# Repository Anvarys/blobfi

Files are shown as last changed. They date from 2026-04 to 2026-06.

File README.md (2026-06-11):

<div align="center">
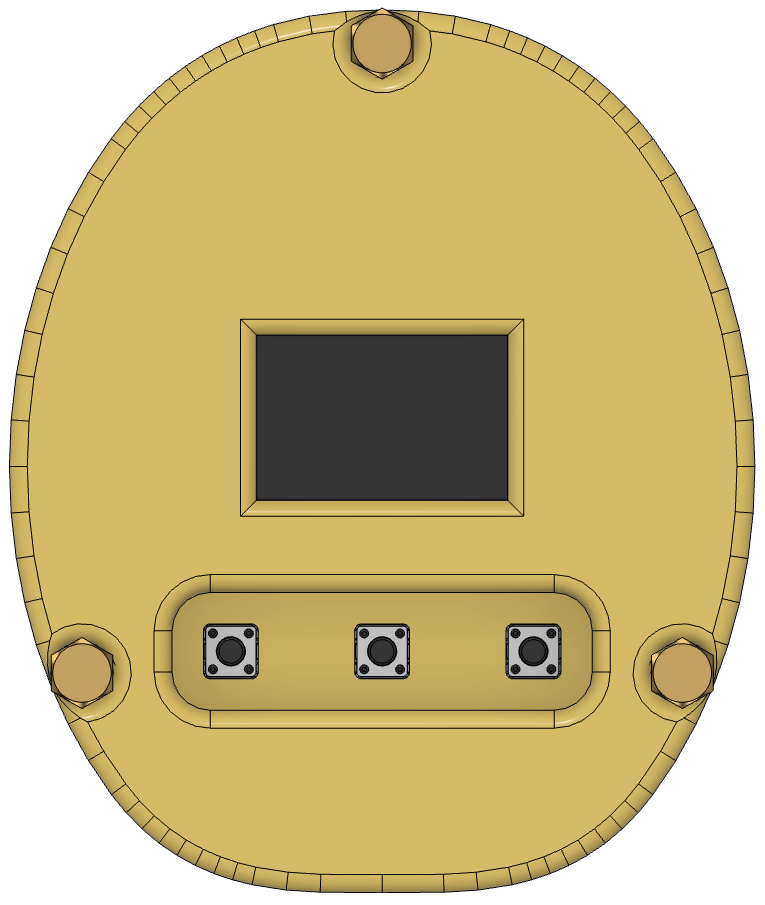
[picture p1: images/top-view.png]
Blobfi
  
</div>

<h2 align="center">Blobfi</h2>
<p align="center">
A custom PCB-based Tamagotchi virtual pet called Blobfi
</p>

## About the project

A custom PCB-based Tamagotchi-like virtual pet built the XIAO-ESP32-C6 MCU, featuring a 0.96" OLED display, 500mah battery with USB-C charging (via the esp32), 3 buttons, a temperature sensor and a vibration motor.

I made this project to have my own custom tamagotchi pet called Blobfi, which is a blobfish, because I love blobfishes!!

I used [Tanishq's tamagotchi](https://github.com/TaniWanKenobi/tamagotchi/) as insiration & reference.

## How to build your own Blobfi

To build this project yourself, first you need to 3d print the top and bottom parts ([link to the folder with 3d models](https://github.com/Anvarys/blobfi/tree/master/CAD)), also you preferably should print 4 of the screen supports that will be used to mount hold the screen parallel to the PCB. Then you need to buy all the [parts](https://github.com/Anvarys/blobfi/blob/master/BOM.csv) and the [PCB](https://github.com/Anvarys/blobfi/blob/master/blobfi_gerber.zip) and then assemple it all together as shown on the picture below (also you need to screw the PCB and the top to the bottom enclosure in using 3 M3x8mm screws each):
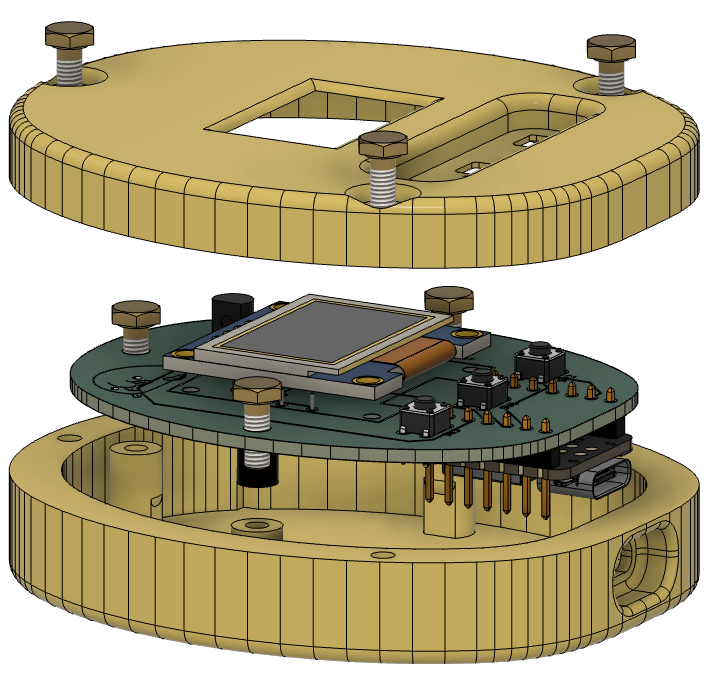
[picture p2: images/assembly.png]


And then you need to flash the ESP32 using my [blobfi_firmware](https://github.com/Anvarys/blobfi/tree/master/blobfi_firmware) sketch in Arduino IDE, also you need to install Adafruit SSD1306, OneWireNg, DallasTemperature libraries with their dependencies.

## Tools I used

For PCB & schematic design I used [KiCAD](https://kicad.org), for 3D design I used [Autodesk Fusion](https://www.autodesk.com/products/fusion-360/overview) (free version), for coding the firmware I used [Arduino IDE](https://www.arduino.cc/en/software/), for testing the firmware I used [Wowki](https://wokwi.com/) hardware simulator and for general design (Edge.Cuts & the Zine) I used [Figma](https://figma.com)

## PCB design

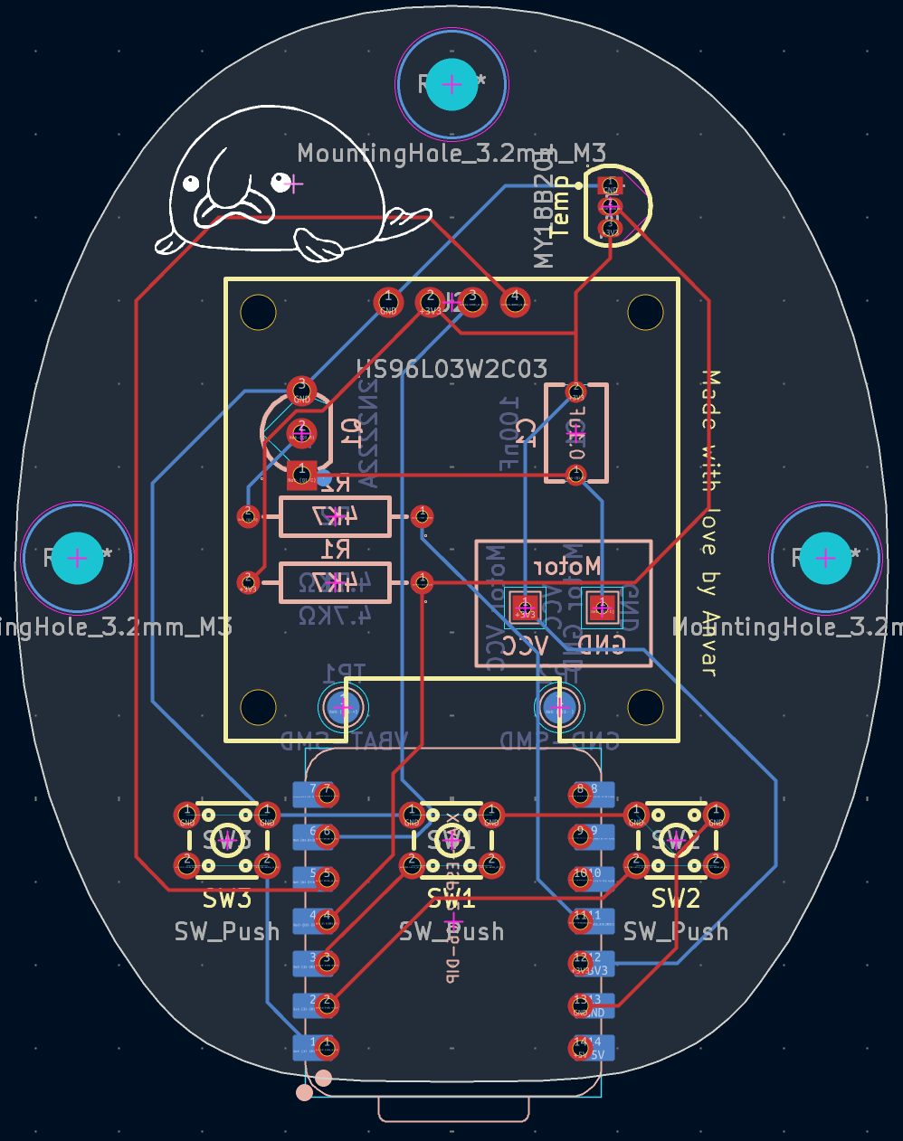
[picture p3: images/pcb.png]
pcb


## Schematic

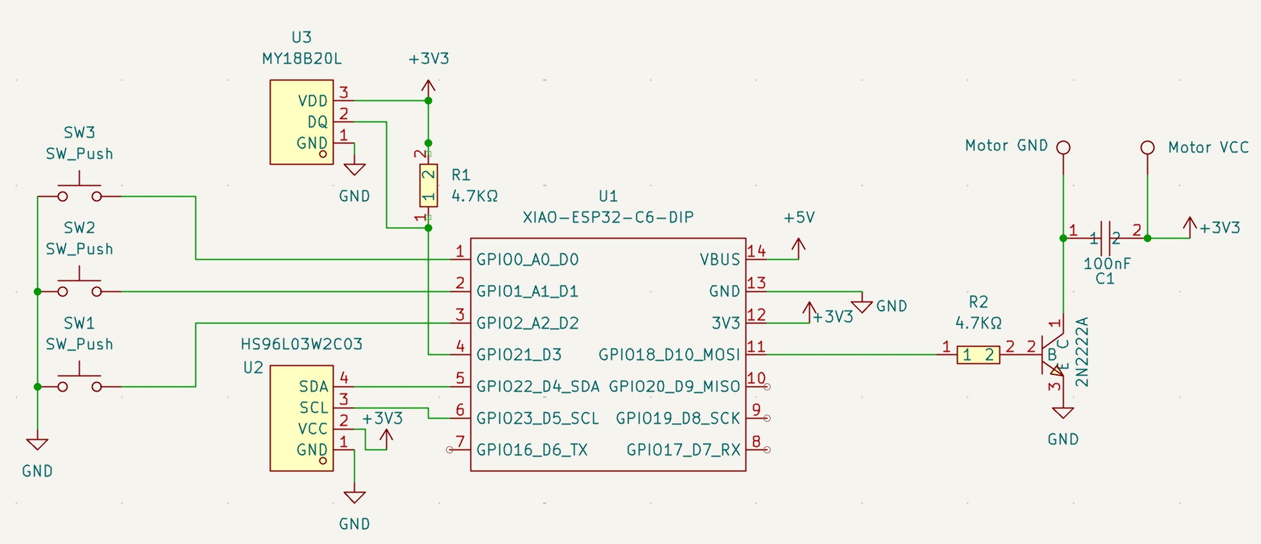
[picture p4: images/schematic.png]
schematic


## 3D model

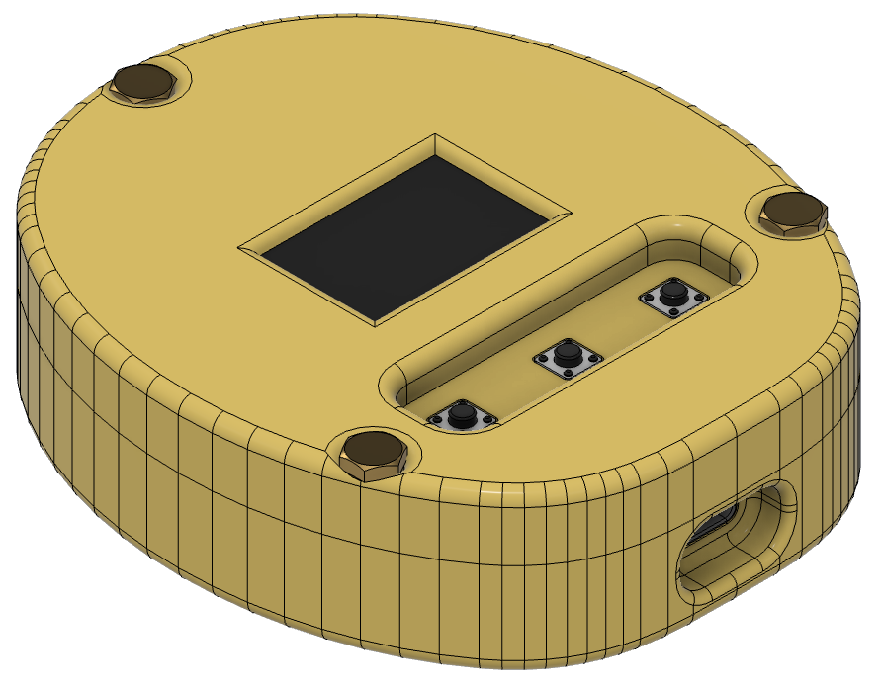
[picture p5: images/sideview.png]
3d model


## Firmware

Blobfi has 3 stats which decrease by 1 each 5 minutes:
- Hunger
- Happiness
- Energy

And if the temperature of Blobfi goes above 40C or below 5C happiness will decrease at 2x rate.

Depending on these stats you will have a different image of a blobfish on your main screen, here is an example of a happy Blobfi:

Emulated render:
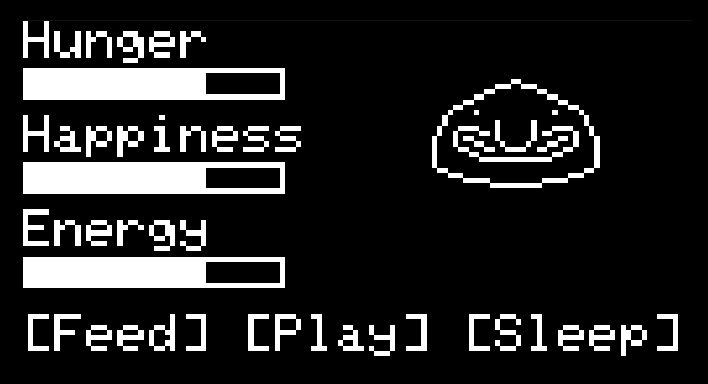
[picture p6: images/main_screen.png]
main_screen


An actual photo:
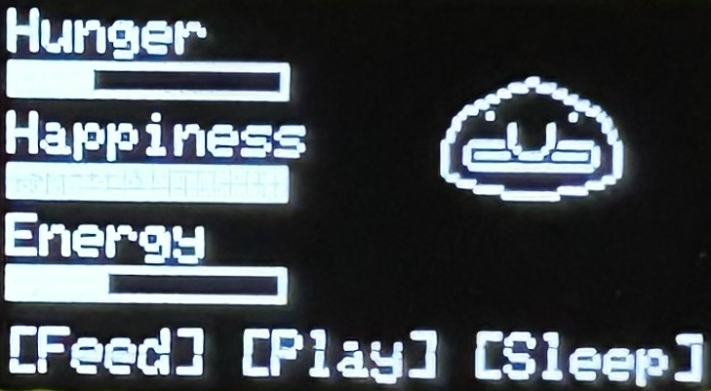
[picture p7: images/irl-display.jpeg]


If any of the stats will go below 0 it will be set to 0 and the vibration motor will shake your Blobfi as it wants to eat/sleep/play.

Also if any stat is below 10 then the bar will blink on the screen.

Actions buttons do:
- Left button: Feed Blobfi, +15 hunger and +5 energy
- Middle button: Play with Blobfi, +15 happiness and -5 energy
- Right button: Put Blobfi to sleep, +15 energy
- Left and right buttons at the same time: Put the device into deep sleep (basically turning it off, you can wake it up by pressing any button)

And here is an example of an action animation (duration - 3s):

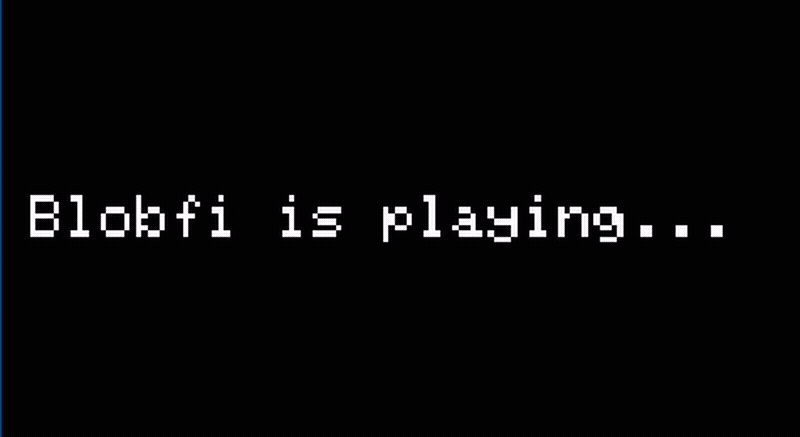
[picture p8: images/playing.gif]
playing animation


#### Deep sleep

Also my firmware uses ESP32 deep sleep feature, which allows it to go into a very low power use mode. After 30 seconds of inactivity (not pressing any buttons) the device will go into deep sleep.

When the device goes into deep sleep it will disable the display, but it will start an internal timer for the next update of Blobfi (5 minutes minus the time from the last update that had already passed) and it will still listen to any button inputs, and if you press any button it will wake up to the normal state.

This allows to reduce ESP32C6 and display's total current from about **50mA** to about **17µA** which is around **2941 times less current**. This allows for the device to actually work for longer than some 10-15 hours, now it can do multiple weeks (theoretically months, has not tested that in practice yet).

## BOM

|Name |Price (Total)|Link |
|---|---|---|
|Lithium battery 500mah |US$6.73 |https://fr.aliexpress.com/item/1005009540712263.html|
|XIAO ESP32 C6 |US$6.71 |https://fr.aliexpress.com/item/1005006987272421.html|
|M3 8mm screws |US$3.55 |https://fr.aliexpress.com/item/1005010597960014.html|
|Aliexpress shipping |US$5.10 |- |
|JLCPCB PCB |US$2.00 |https://jlcpcb.com |
|JLCPCB shipping & customs|US$2.20 |- |
|4K7 Resistor |US$0.58 |https://www.lcsc.com/product-detail/C119339.html |
|MY18B20L temp sensor |US$1.94 |https://www.lcsc.com/product-detail/C5259249.html |
|0.96'' OLED display |US$2.25 |https://www.lcsc.com/product-detail/C5248080.html |
|Tactile button |US$0.54 |https://www.lcsc.com/product-detail/C2888493.html |
|Vibration motor |US$0.52 |https://www.lcsc.com/product-detail/C2759982.html |
|Male pin headers (20pcs) |US$0.60 |https://www.lcsc.com/product-detail/C49261205.html  |
|2N2222A transistor |US$0.90 |https://www.lcsc.com/product-detail/C5330385.html |
|0.1uF capacitor |US$0.61 |https://www.lcsc.com/product-detail/C5632427.html |
|LCSC shipping & handling |US$12.57 |- |
| | | |
|Total |US$46.80 | |

The display is out of stock so the price is for buying one from "Other suppliers" on LCSC

## Build photos

For reference the squares are 5x5mm

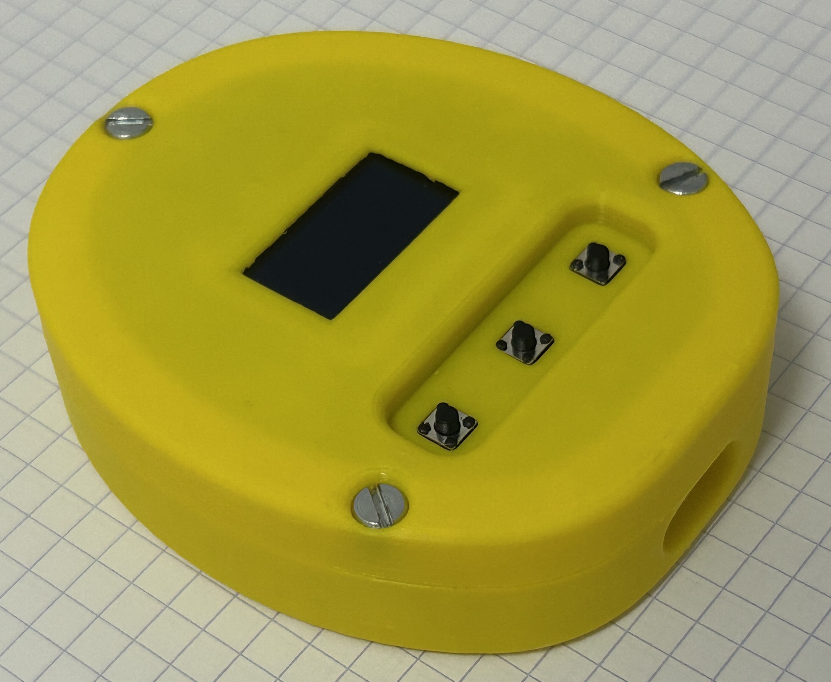
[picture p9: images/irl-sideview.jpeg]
sideview


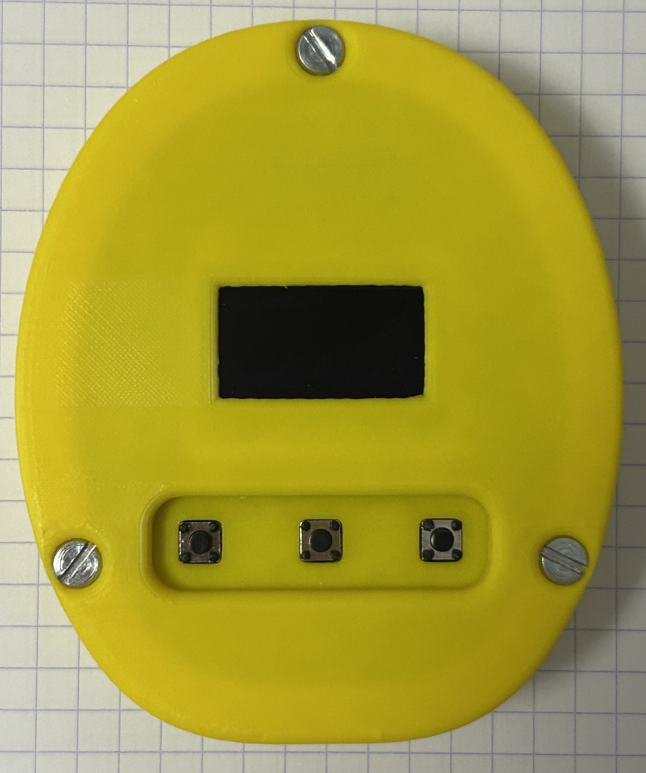
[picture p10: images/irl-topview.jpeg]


[_demo_](https://www.youtube.com/shorts/axdSh3g87GE)

## My zine for this project

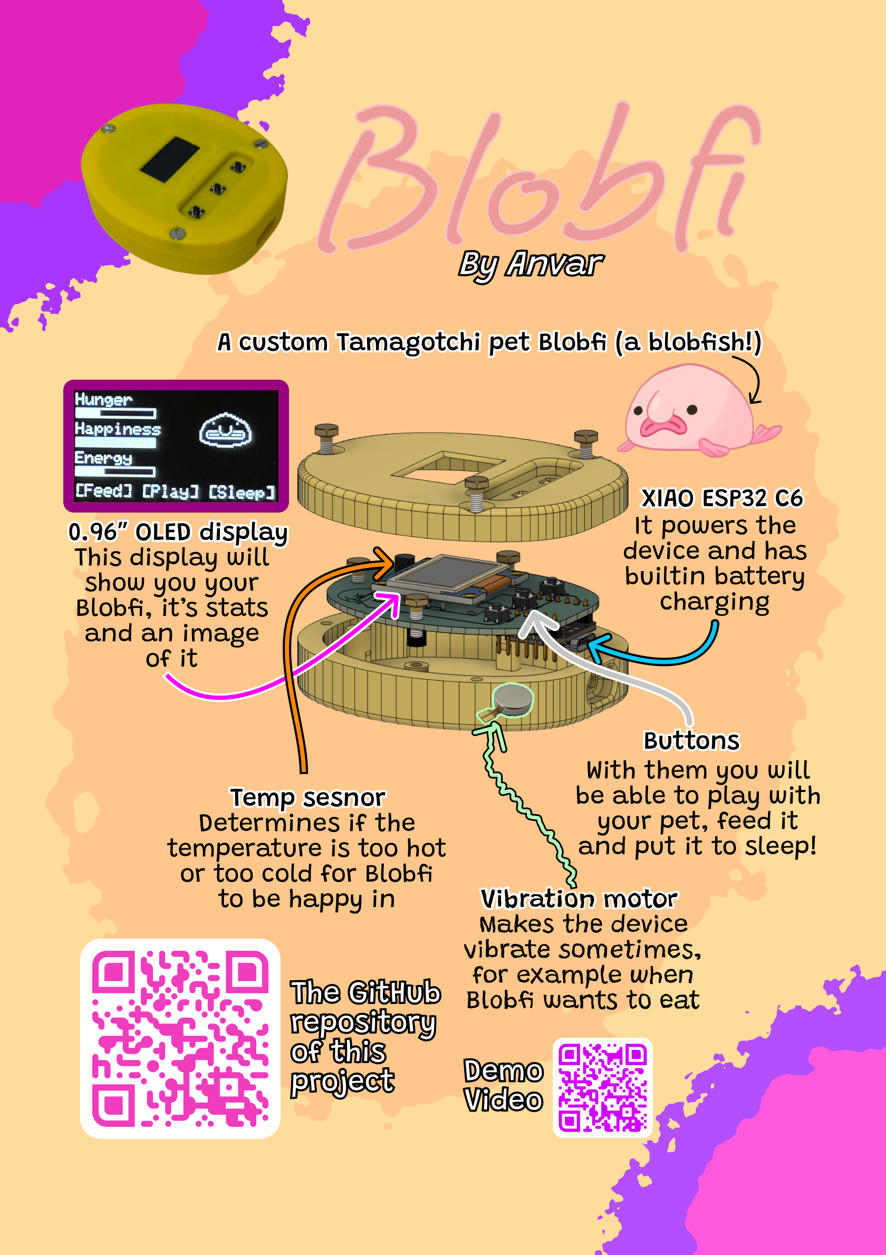
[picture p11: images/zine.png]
Zine


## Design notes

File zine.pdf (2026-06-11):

## Blobfi By Anvar

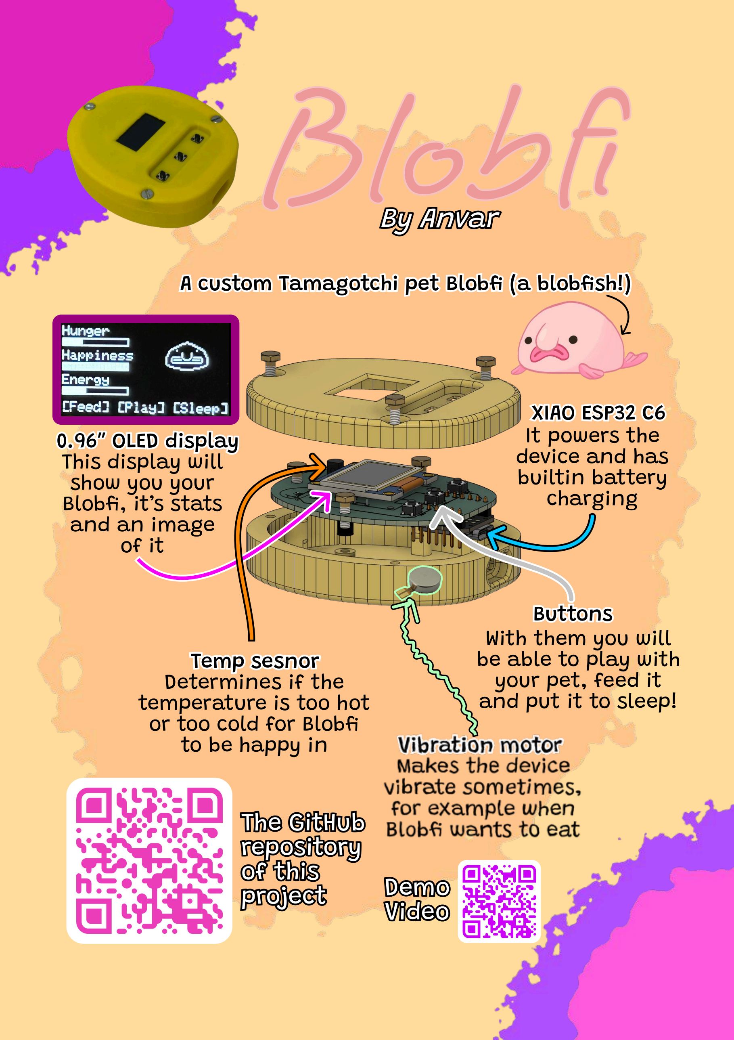
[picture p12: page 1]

A custom Tamagotchi pet Blobfi (a blobfish!)

0.96’’ OLED display This display will show you your Blobfi, it’s stats and an image of it

XIAO ESP32 C6
It powers the device and has builtin battery

charging

Determines if the temperature is too hot or too cold for Blobfi to be happy in

Temp sesnor

### The GitHub repository of this

project

aes the device vibrate sometimes, for eample when Blobfi wants to eat

### Demo

Video

ibration motor

Buttons
With them you will be able to play with your pet, feed it and put it to sleep!

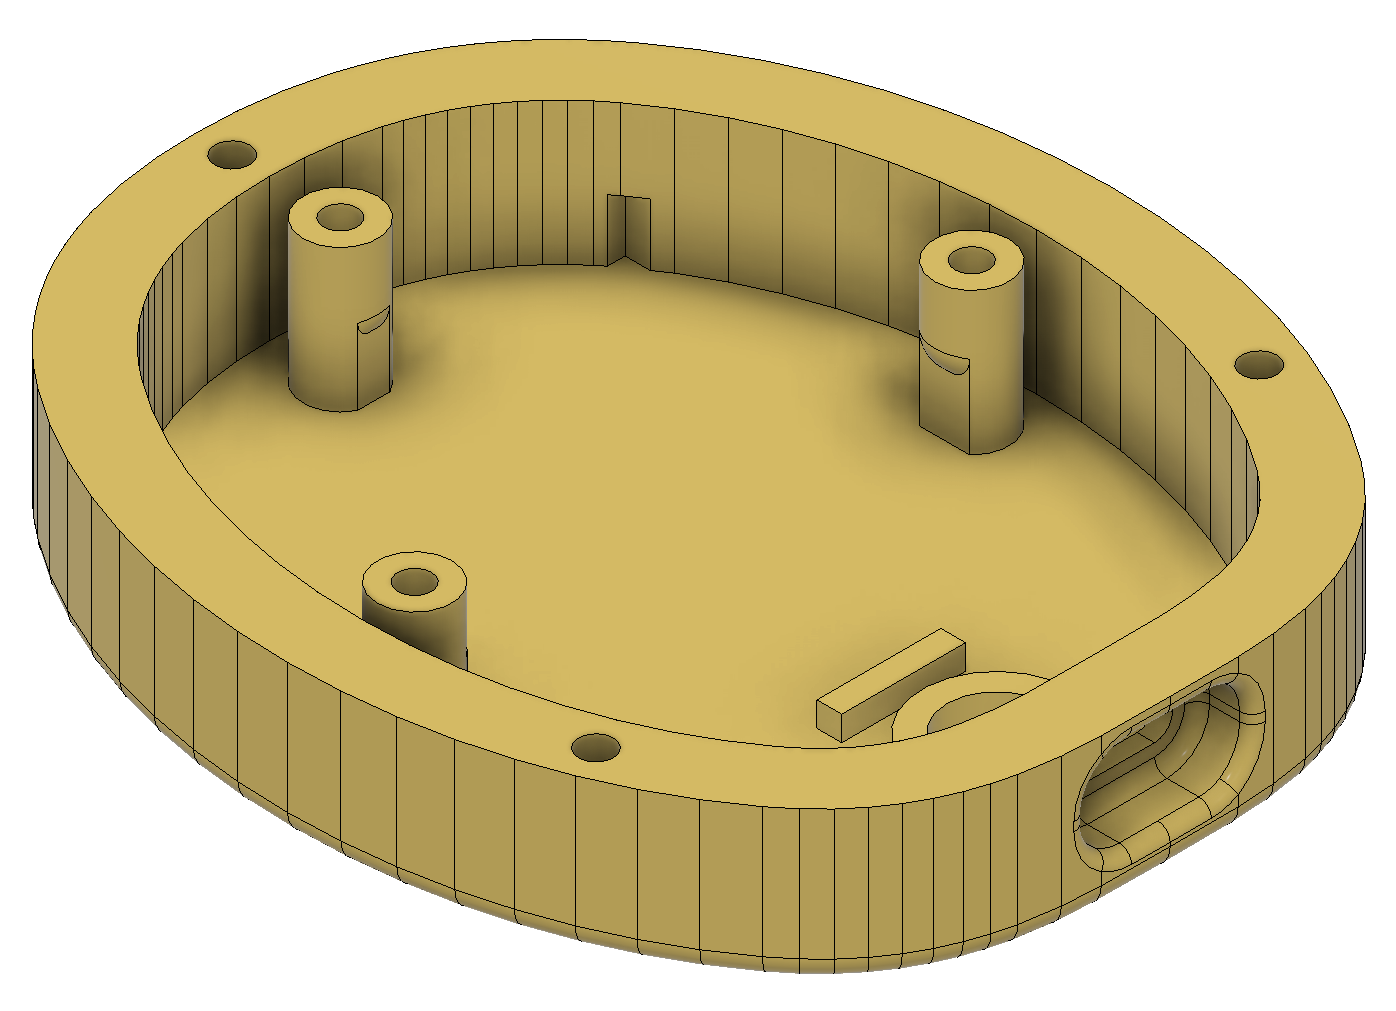
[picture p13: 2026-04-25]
images/bottom-3d-model.png

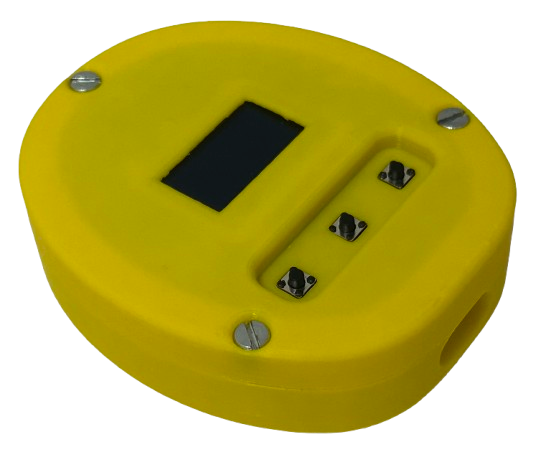
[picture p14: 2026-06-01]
images/irl-sideview-no-bg.png

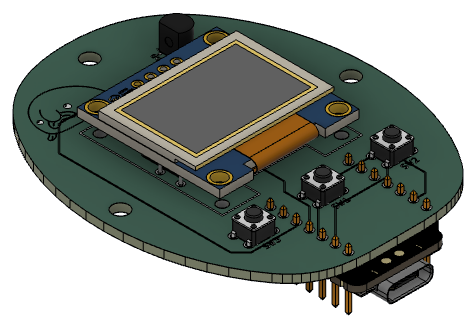
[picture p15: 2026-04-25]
images/pcb-3d-model.png

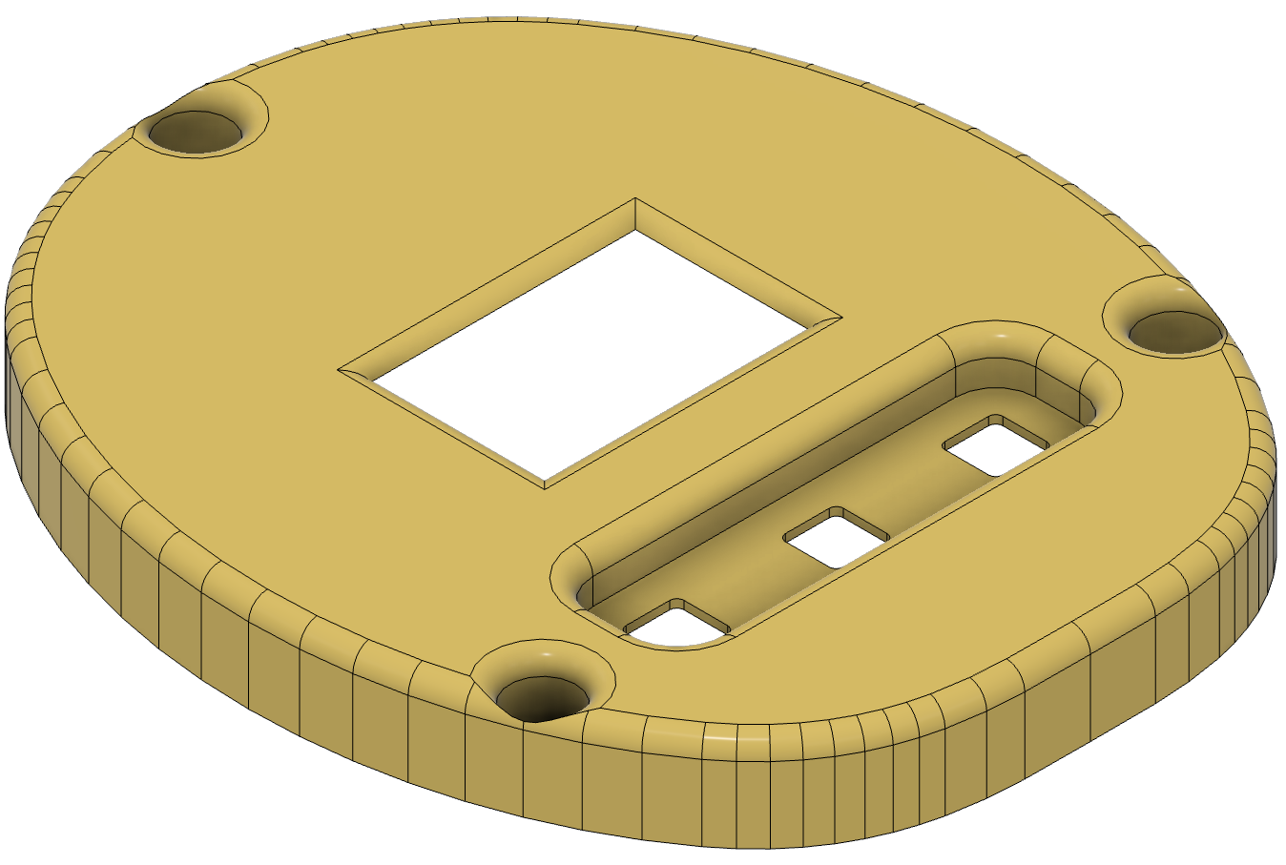
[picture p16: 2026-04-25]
images/top-3d-model.png

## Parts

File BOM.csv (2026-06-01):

Name | Qty needed | Qty bought | Link | Price (Qty bought) | Running total | Note
LED driver | 1 | 1 | https://www.lcsc.com/product-detail/C157417.html | US$3.29 | US$3.29
LED | 72 | 80 | https://www.lcsc.com/product-detail/C17215415.html | US$0.94 | US$4.23
RP2040 MCU | 1 | 1 | https://www.lcsc.com/product-detail/C2040.html | US$0.95 | US$5.18
USB-C PD controller | 1 | 1 | https://www.lcsc.com/product-detail/C970725.html | US$0.61 | US$5.79
USB-C port | 1 | 5 | https://www.lcsc.com/product-detail/C7463258.html | US$1.20 | US$6.99
Step-down buck converter to 3.3V | 1 | 1 | https://www.lcsc.com/product-detail/C60726.html | US$1.32 | US$8.31
12MHz crystal | 1 | 5 | https://www.lcsc.com/product-detail/C2901650.html | US$0.38 | US$8.69
32Mbit flash | 1 | 1 | https://www.lcsc.com/product-detail/C179173.html | US$1.66 | US$10.35 | can be interchanged with any memory size of the same family (up to 128Mbit)
RTC IC | 1 | 1 | https://www.lcsc.com/product-detail/C107410.html | US$3.01 | US$13.36
Coin battery holder | 1 | 1 | https://www.lcsc.com/product-detail/C7501066.html | US$0.82 | US$14.18
6P Socket for the display | 1 | 6 | https://www.lcsc.com/product-detail/C2897388.html | US$0.99 | US$15.17
Step-down buck converter to 10.5V | 1 | 5 | https://www.lcsc.com/product-detail/C52653.html | US$2.03 | US$17.20
Capacitive touch IC | 3 | 3 | https://www.lcsc.com/product-detail/C91322.html | US$9.56 | US$26.76
Buzzer | 1 | 1 | https://www.lcsc.com/product-detail/C255333.html | US$1.17 | US$27.93
NPN transitor | 1 | 5 | https://www.lcsc.com/product-detail/C7603172.html | US$0.04 | US$27.97
AO3401A | 1 | 10 | https://www.lcsc.com/product-detail/C15127.html | US$0.59 | US$28.56
AO3400A | 1 | 5 | https://www.lcsc.com/product-detail/C20917.html | US$0.41 | US$28.97
3.3uH inductor | 2 | 5 | https://www.lcsc.com/product-detail/C167219.html | US$0.85 | US$29.82
B220A diode | 2 | 5 | https://www.lcsc.com/product-detail/C110481.html | US$0.47 | US$30.29
Tactile button | 1 | 10 | https://www.lcsc.com/product-detail/C49140441.html | US$0.42 | US$30.71
6.8pF capacitor | 1 | 50 | https://www.lcsc.com/product-detail/C318672.html | US$0.53 | US$31.24
15pF capacitor | 2 | 100 | https://www.lcsc.com/product-detail/C1644.html | US$0.60 | US$31.84
180pF capacitor | 1 | 100 | https://www.lcsc.com/product-detail/C107041.html | US$0.43 | US$32.27
10nF capacitor | 1 | 50 | https://www.lcsc.com/product-detail/C1589.html | US$0.20 | US$32.47
0.1uF capacitor | 20 | 50 | https://www.lcsc.com/product-detail/C15725.html | US$0.35 | US$32.82
1uF capacitor | 4 | 50 | https://www.lcsc.com/product-detail/C5199872.html | US$0.45 | US$33.27
2.2uF capacitor | 1 | 10 | https://www.lcsc.com/product-detail/C19110.html | US$0.19 | US$33.46
10uF capacitor | 3 | 10 | https://www.lcsc.com/product-detail/C9807.html | US$0.39 | US$33.85
22uF capacitor | 2 | 10 | https://www.lcsc.com/product-detail/C602037.html | US$0.43 | US$34.28
27Ω resistor | 3 | 100 | https://www.lcsc.com/product-detail/C25190.html | US$0.15 | US$34.43
249Ω ±0.1% resistor | 3 | 10 | https://www.lcsc.com/product-detail/C870575.html | US$0.73 | US$35.16 | ±0.1% because it controls LED driver's max output intensity
1kΩ resistor | 2 | 100 | https://www.lcsc.com/product-detail/C2907113.html | US$0.11 | US$35.27
1kΩ 500mW resistor | 2 | 2 | https://www.lcsc.com/product-detail/C966306.html | US$0.01 | US$35.28 | R1, R2: usb-c PD, required ≥400mW
10kΩ resistor | 6 | 20 | https://www.lcsc.com/product-detail/C95204.html | US$0.44 | US$35.72 | ±0.1% resistor, not required but recommended for R26, controls the 10.5V Vout of a converter
4.7kΩ resistor | 2 | 100 | https://www.lcsc.com/product-detail/C2907034.html | US$0.12 | US$35.84
100kΩ ±0.1% resistor | 2 | 20 | https://www.lcsc.com/product-detail/C122538.html | US$0.45 | US$36.29 | ±0.1% because it controls 3.3V Vout of a converter (R5)
1MΩ resistor | 1 | 100 | https://www.lcsc.com/product-detail/C2907115.html | US$0.11 | US$36.40
75kΩ resistor | 3 | 100 | https://www.lcsc.com/product-detail/C114636.html | US$0.16 | US$36.56
47kΩ resistor | 1 | 100 | https://www.lcsc.com/product-detail/C105579.html | US$0.16 | US$36.72
316kΩ ±0.1% resistor | 1 | 20 | https://www.lcsc.com/product-detail/C861833.html | US$0.55 | US$37.27 | ±0.1% because it controls 3.3V Vout of a converter (R6)
121kΩ resistor | 1 | 20 | https://www.lcsc.com/product-detail/C861095.html | US$0.52 | US$37.79 | ±0.1% resistor, not required but recommended for R27, controls the 10.5V Vout of a converter
LCSC FedEx fast shipping |  |  | - | US$29.40 | US$67.19 | Without fast shipping I won't be able to build it in time
LCSC shipping coupon |  |  |  | -US$5.00 | US$62.19
JLCPCB PCB + stencil | 1 | 5 | https://jlcpcb.com | US$18.21 | US$80.40
JLCPCB DHL fast shipping |  |  | - | US$24.94 | US$105.34
JLCPCB customs |  |  |  | US$6.63 | US$111.97
JLCPCB shipping coupon |  |  |  | -US$10.00 | US$101.97 | New user shipping coupon
M2.5 5mm screws | 9 | 50 | https://www.amazon.fr/Inovey-Stainless-Hexagon-Ultrathin-Socket/dp/B0D59JTN94 | US$5.85 | US$107.82 | flat head, must have: dk <= 6.5mm && k <= 1.4mm | there are cheaper options on aliexpress, but if you need it to ship fast, amazon is the cheapest option
M3 6mm screws | 5 | 50 | https://www.amazon.fr/Inovey-Stainless-Hexagon-Ultrathin-Socket/dp/B0D59JTN94 | US$5.85 | US$113.67 | flat head, must have: dk <= 6.5mm && k <= 1.4mm | there are cheaper options on aliexpress, but if you need it to ship fast, amazon is the cheapest option
Waveshare 2.42" display | 1 | 1 | https://www.amazon.fr/Waveshare-Resolution-Communication-Compatible-Raspberry/dp/B0CL6WMHJN | US$25.64 | US$139.31 | there are cheaper options on aliexpress, but if you need it to ship fast, amazon is the cheapest option
Fan 12V | 1 | 1 | https://fr.aliexpress.com/item/1005002566049059.html | US$2.87 | US$142.18
3D printing Filament | 80g | 1kg | https://www.amazon.fr/ELEGOO-Imprimante-Précision-Dimensionnelle-Imprimantes/dp/B0D4Z8QT5T | US$21.04 | US$163.22 | preferably matte
Total |  |  |  | US$163.22

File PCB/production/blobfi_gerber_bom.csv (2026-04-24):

Designator | Footprint | Quantity | Value | LCSC Part #
C1 | CAP-TH_L5.8-W3.6-P5.0-D0.6 | 1 | 100nF | C5632427
GND | TestPoint_THTPad_1.5x1.5mm_Drill0.7mm | 1 | Motor GND
Q1 | TO-92-3_L4.8-W3.7-P2.54-R | 1 | 2N2222A | C5330385
R1, R2 | RES-TH_BD2.3-L6.5-P10.50-D0.5 | 2 | 4.7KΩ | C119339
SW1, SW2, SW3 | SW-TH_4P-L4.5-W4.5-P3.00-LS4.8 | 3 | SW_Push
TEMP | TO-92-3_L4.8-W3.7-P1.27-L | 1 | MY18B20L | C5259249
TP1 | TestPoint_Pad_D2.0mm | 1 | VBAT-SMD
TP2 | TestPoint_Pad_D2.0mm | 1 | GND-SMD
U1 | XIAO-ESP32-C6-DIP | 1 | XIAO-ESP32-C6-DIP
U2 | OLED-TH_L27.8-W27.2-P2.54_C9900033791 | 1 | HS96L03W2C03 | C5248080
VCC | TestPoint_THTPad_1.5x1.5mm_Drill0.7mm | 1 | Motor VCC

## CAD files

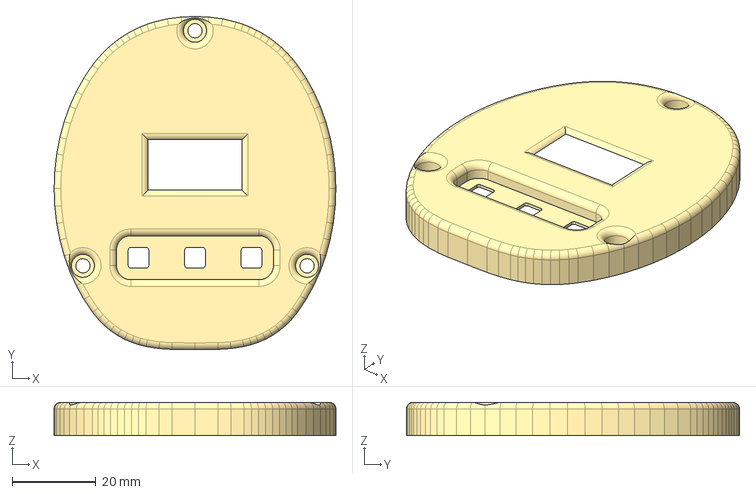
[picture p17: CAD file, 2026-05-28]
CAD/top-part.step
67.3 x 79.6 x 8.00 mm

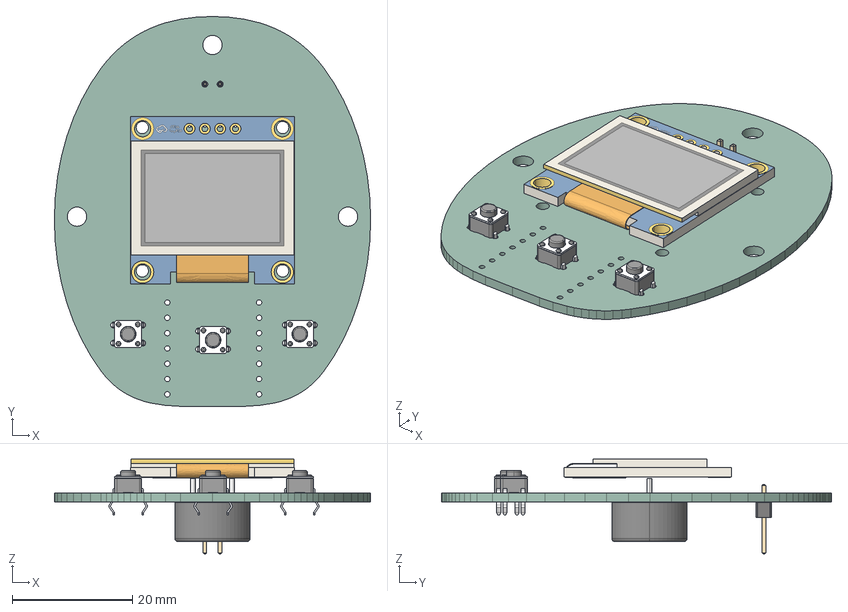
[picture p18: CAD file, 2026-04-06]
PCB/export/blobfi_pcb.step
52.5 x 64.8 x 15.7 mm
OLED-TH_L27.8-W27.2-P2.54_C9900033791
BUZ-TH_BD12.5-H7.0-P6.5
PinHeader_1x02_P2.54mm_Vertical
blobfi_PCB

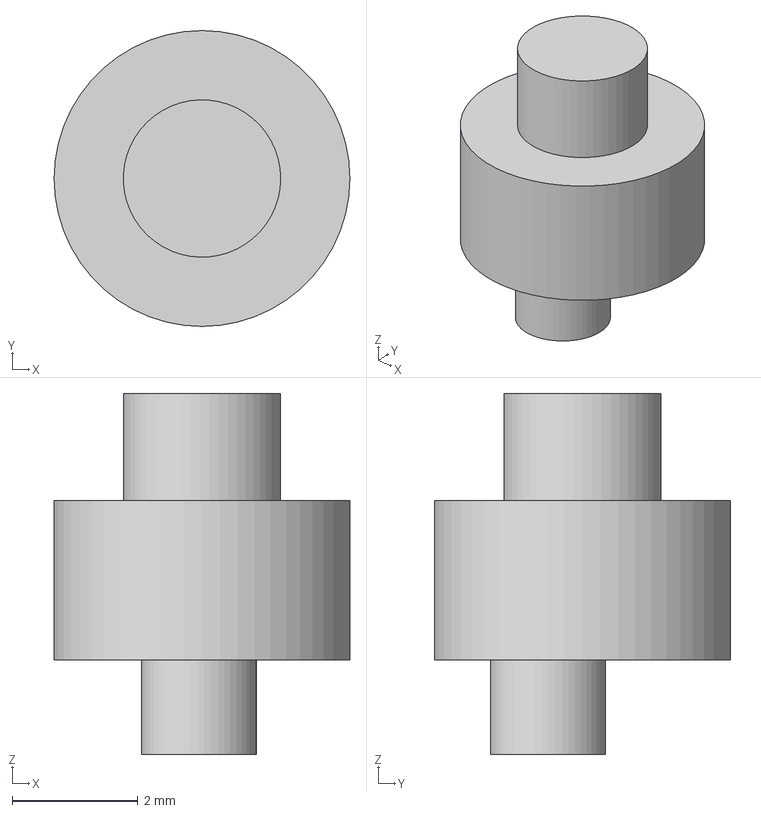
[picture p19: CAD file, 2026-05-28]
CAD/screen-support.step
4.70 x 4.70 x 5.74 mm

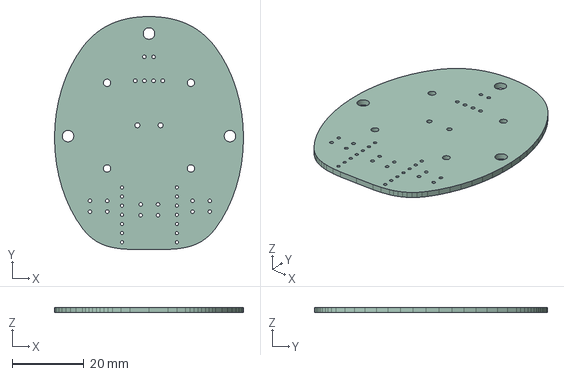
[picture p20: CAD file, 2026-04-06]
PCB/export/blobfi_pcb_only.step
52.5 x 64.8 x 1.51 mm

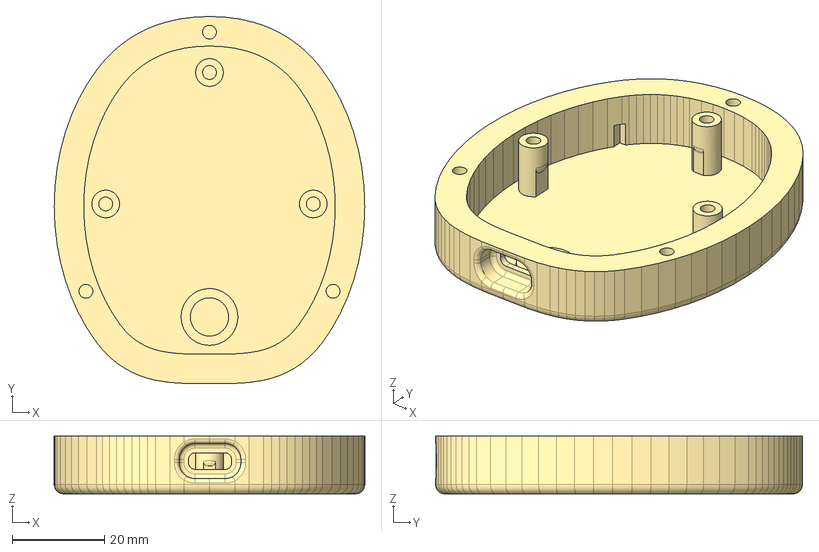
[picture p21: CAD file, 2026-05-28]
CAD/bottom-part.step
67.3 x 79.6 x 12.5 mm

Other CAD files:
CAD/bottom-part.f3d
CAD/top-part.f3d

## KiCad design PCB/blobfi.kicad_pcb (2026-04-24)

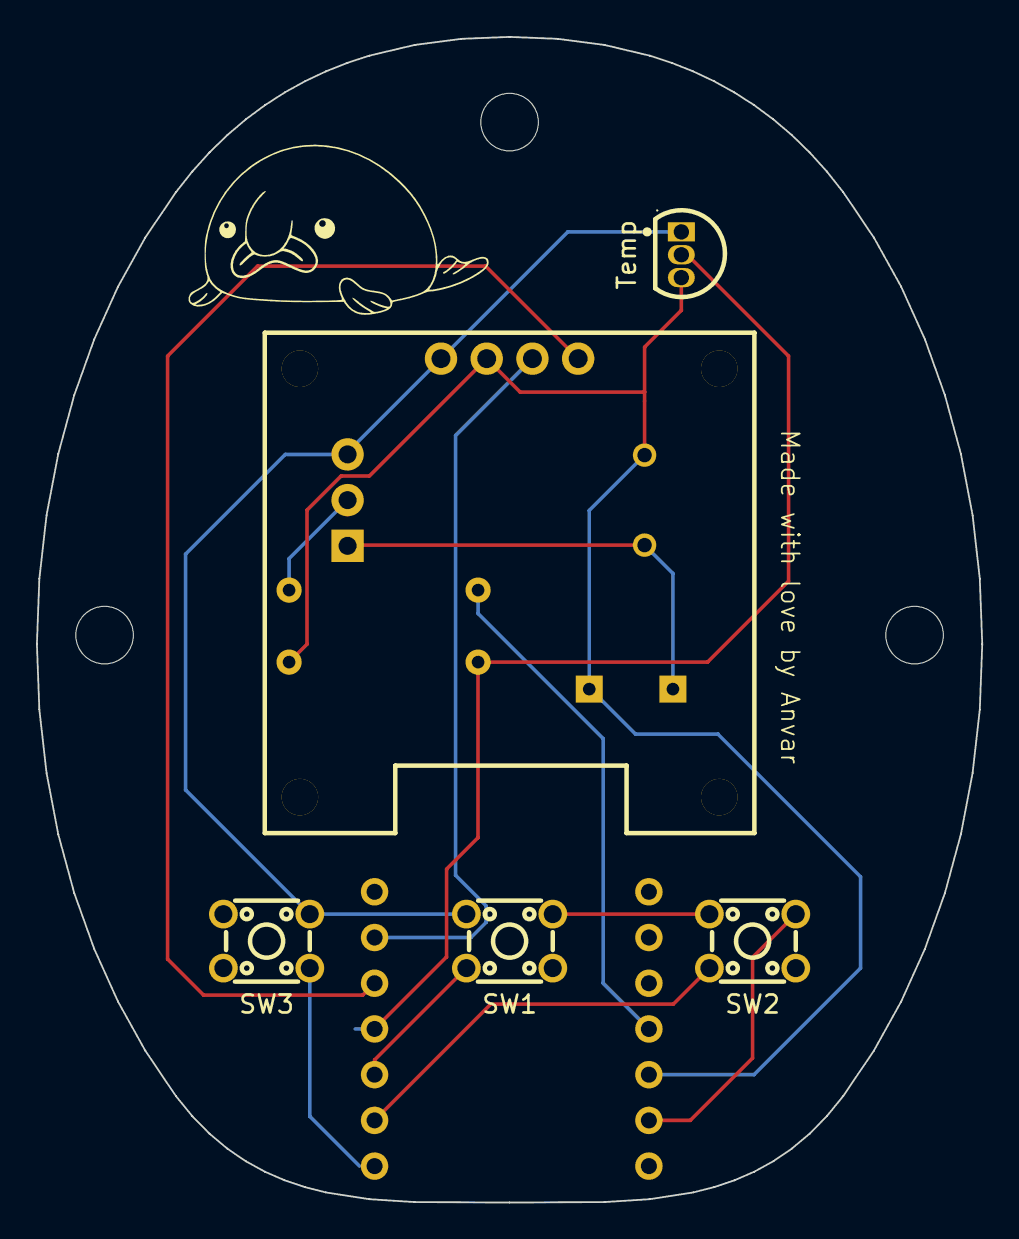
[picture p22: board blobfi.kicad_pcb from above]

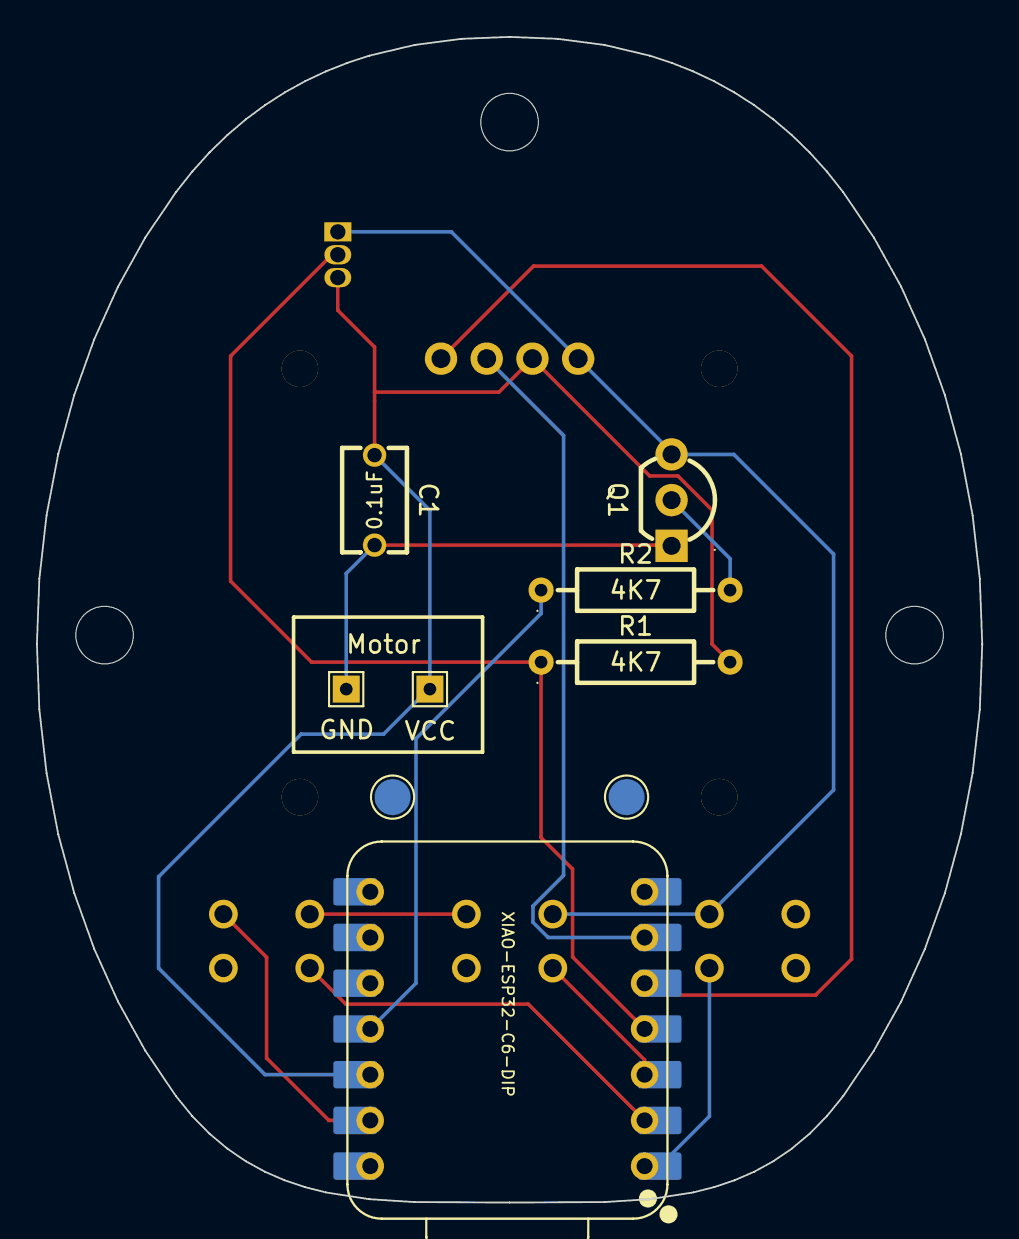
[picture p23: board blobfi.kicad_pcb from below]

Board: 2 copper layers, 52.5 x 64.8 mm, 14 parts (9 on the bottom side), 11 nets.

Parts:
C1: 100nF; CAP-TH_L5.8-W3.6-P5.0-D0.6
GND: Motor GND; TestPoint_THTPad_1.5x1.5mm_Drill0.7mm
Q1: 2N2222A; TO-92-3_L4.8-W3.7-P2.54-R
R1, R2: 4.7KΩ; RES-TH_BD2.3-L6.5-P10.50-D0.5
SW1, SW2, SW3: SW_Push; SW-TH_4P-L4.5-W4.5-P3.00-LS4.8
TP1: VBAT-SMD; TestPoint_Pad_D2.0mm
TP2: GND-SMD; TestPoint_Pad_D2.0mm
Temp: MY18B20L; TO-92-3_L4.8-W3.7-P1.27-L
U1: XIAO-ESP32-C6-DIP
U2: HS96L03W2C03; OLED-TH_L27.8-W27.2-P2.54_C9900033791
VCC: Motor VCC; TestPoint_THTPad_1.5x1.5mm_Drill0.7mm

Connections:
+3V3: C1.2, R1.2, Temp.3 (VDD), U1.12 (3V3), U2.2 (VCC), VCC.1 (1_1)
GND: Q1.3 (E), SW1.1, SW2.1, SW3.1, Temp.1 (GND), U1.13 (GND), U2.1 (GND)
unnamed: Q1.2 (B), R2.2
unnamed: C1.1, GND.1 (1_1), Q1.1 (C)
unnamed: SW3.2, U1.1 (GPIO0_A0_D0)
unnamed: SW2.2, U1.2 (GPIO1_A1_D1)
unnamed: SW1.2, U1.3 (GPIO2_A2_D2)
unnamed: R2.1, U1.11 (GPIO18_D10_MOSI)
unnamed: R1.1, Temp.2 (DQ), U1.4 (GPIO21_D3)
unnamed: U1.5 (GPIO22_D4_SDA), U2.4 (SDA)
unnamed: U1.6 (GPIO23_D5_SCL), U2.3 (SCL)

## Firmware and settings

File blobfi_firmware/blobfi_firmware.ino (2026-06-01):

#include <Arduino.h>
#include <Wire.h>
#include <Adafruit_SSD1306.h>
#include <Adafruit_GFX.h>
#include <OneWireNg_CurrentPlatform.h>
#include <drivers/DSTherm.h>
#include <utils/Placeholder.h>


#define WIDTH 128
#define HEIGHT 64
#define OLED_RESET -1

#define BTN_LEFT 0
#define BTN_MIDDLE 2
#define BTN_RIGHT 1
#define VIBRATION_MOTOR 18
#define TEMP_SENSOR 21

#define BTN_LEFT_PIN_BITMASK (1ULL << GPIO_NUM_0)
#define BTN_MIDDLE_PIN_BITMASK (1ULL << GPIO_NUM_1)
#define BTN_RIGHT_PIN_BITMASK (1ULL << GPIO_NUM_2)

#define UPDATE_DELAY_IN_S 300
#define UPDATE_DELAY_IN_uS (UPDATE_DELAY_IN_S * 1000000ULL)

#define SLEEP_AFTER_INACTIVE_FOR_S 30

Adafruit_SSD1306 display(WIDTH, HEIGHT, &Wire, OLED_RESET);

OneWireNg_CurrentPlatform ow(TEMP_SENSOR, false);
DSTherm therm(ow);
Placeholder<DSTherm::Scratchpad> scratchpad;

OneWireNg::Id sensorId;

const unsigned char PROGMEM NEUTRAL_BLOBFI[] = {
  0b00000000, 0b00000000, 0b00000000, 0b00000000,
  0b00000000, 0b00000001, 0b10000000, 0b00000000,
  0b00000000, 0b00001110, 0b01110000, 0b00000000,
  0b00000000, 0b00110000, 0b00001100, 0b00000000,
  0b00000000, 0b11000000, 0b00000011, 0b00000000,
  0b00000011, 0b00000000, 0b00000000, 0b11000000,
  0b00001100, 0b00000000, 0b00000000, 0b00110000,
  0b00010000, 0b10000000, 0b00000001, 0b00001000,
  0b00100000, 0b00000000, 0b00000000, 0b00000100,
  0b00100000, 0b00001000, 0b00010000, 0b00000100,
  0b01000000, 0b00001000, 0b00010000, 0b00000010,
  0b01000000, 0b00001000, 0b00010000, 0b00000010,
  0b10000111, 0b11101000, 0b00010111, 0b11100001,
  0b10001000, 0b00000100, 0b00100000, 0b00010001,
  0b10001011, 0b11110011, 0b11001111, 0b11010001,
  0b10001000, 0b00000000, 0b00000000, 0b00010001,
  0b10000111, 0b11111111, 0b11111111, 0b11100001,
  0b10000000, 0b00000000, 0b00000000, 0b00000001,
  0b01100000, 0b00000000, 0b00000000, 0b00000110,
  0b00011100, 0b00000000, 0b00000000, 0b00111000,
  0b00000011, 0b11100000, 0b00000111, 0b11000000,
  0b00000000, 0b00011111, 0b11111000, 0b00000000
};

const unsigned char PROGMEM HAPPY_BLOBFI[] = {
  0b00000000, 0b00000000, 0b00000000, 0b00000000,
  0b00000000, 0b00000001, 0b10000000, 0b00000000,
  0b00000000, 0b00001110, 0b01110000, 0b00000000,
  0b00000000, 0b00110000, 0b00001100, 0b00000000,
  0b00000000, 0b11000000, 0b00000011, 0b00000000,
  0b00000011, 0b00000000, 0b00000000, 0b11000000,
  0b00001100, 0b00000000, 0b00000000, 0b00110000,
  0b00010000, 0b10000000, 0b00000001, 0b00001000,
  0b00100000, 0b00000000, 0b00000000, 0b00000100,
  0b00100000, 0b00001000, 0b00010000, 0b00000100,
  0b01000111, 0b10001000, 0b00010001, 0b11100010,
  0b01001000, 0b01101000, 0b00010110, 0b00010010,
  0b10001011, 0b00001000, 0b00010000, 0b11010001,
  0b10001000, 0b11000100, 0b00100011, 0b00010001,
  0b10000110, 0b00110011, 0b11001100, 0b01100001,
  0b10000001, 0b10000000, 0b00000001, 0b10000001,
  0b10000000, 0b01111111, 0b11111110, 0b00000001,
  0b10000000, 0b00000000, 0b00000000, 0b00000001,
  0b01100000, 0b00000000, 0b00000000, 0b00000110,
  0b00011100, 0b00000000, 0b00000000, 0b00111000,
  0b00000011, 0b11100000, 0b00000111, 0b11000000,
  0b00000000, 0b00011111, 0b11111000, 0b00000000
};

const unsigned char PROGMEM SAD_BLOBFI[] = {
  0b00000000, 0b00000000, 0b00000000, 0b00000000,
  0b00000000, 0b00000001, 0b10000000, 0b00000000,
  0b00000000, 0b00001110, 0b01110000, 0b00000000,
  0b00000000, 0b00110000, 0b00001100, 0b00000000,
  0b00000000, 0b11000000, 0b00000011, 0b00000000,
  0b00000011, 0b00000000, 0b00000000, 0b11000000,
  0b00001100, 0b00000000, 0b00000000, 0b00110000,
  0b00010000, 0b10000000, 0b00000001, 0b00001000,
  0b00100000, 0b00000000, 0b00000000, 0b00000100,
  0b00100000, 0b00001000, 0b00010000, 0b00000100,
  0b01000000, 0b00001000, 0b00010000, 0b00000010,
  0b01000000, 0b00001000, 0b00010000, 0b00000010,
  0b10000001, 0b11101000, 0b00010111, 0b10000001,
  0b10001110, 0b00000100, 0b00100000, 0b01110001,
  0b10010000, 0b11110011, 0b11001111, 0b00001001,
  0b10010111, 0b00000000, 0b00000000, 0b11101001,
  0b10010000, 0b01111111, 0b11111110, 0b00001001,
  0b10001111, 0b10000000, 0b00000001, 0b11110001,
  0b01100000, 0b00000000, 0b00000000, 0b00000110,
  0b00011100, 0b00000000, 0b00000000, 0b00111000,
  0b00000011, 0b11100000, 0b00000111, 0b11000000,
  0b00000000, 0b00011111, 0b11111000, 0b00000000
};

struct Pet {
  int hunger;
  int happiness;
  int energy;
  unsigned long age; // = AGE_SECONDS / UPDATE_DELAY_IN_S
};

RTC_DATA_ATTR Pet pet = {80, 80, 80, 0};

RTC_DATA_ATTR uint64_t lastUpdate = -1; // uS

uint64_t lastUpdateBootRelative = 0; // uS

suseconds_t getRtcTime() {
  struct timeval tv;
  gettimeofday(&tv, NULL);
  return tv.tv_sec * 1000000ULL + tv.tv_usec;
}

float getTempC() {
  therm.convertTemp(sensorId, 100, false);
  therm.readScratchpad(sensorId, &scratchpad[0]);
  return scratchpad -> getTemp() / 1000.0f;
}

uint64_t lastButtonPress = 0;
uint8_t lastTickButtonPressed = 52;
uint8_t beforeLastTickButtonPressed = 52;

void setup() {
  pinMode(BTN_LEFT, INPUT_PULLUP);
  pinMode(BTN_MIDDLE, INPUT_PULLUP);
  pinMode(BTN_RIGHT, INPUT_PULLUP);
  pinMode(VIBRATION_MOTOR, OUTPUT);

  Serial.begin(115200);

  uint64_t mask = BTN_LEFT_PIN_BITMASK | BTN_MIDDLE_PIN_BITMASK | BTN_RIGHT_PIN_BITMASK;
  esp_deep_sleep_enable_gpio_wakeup(mask, ESP_GPIO_WAKEUP_GPIO_LOW);

  esp_sleep_enable_timer_wakeup(UPDATE_DELAY_IN_uS);

  ow.searchReset();
  Serial.println(ow.search(sensorId));
  therm.writeScratchpad(sensorId, 0, 0, DSTherm::RES_9_BIT);

  if (esp_sleep_get_wakeup_cause() == ESP_SLEEP_WAKEUP_TIMER) {
    updatePet();
    esp_deep_sleep_start();
    return;
  } else if (esp_sleep_get_wakeup_cause() == ESP_SLEEP_WAKEUP_EXT1) {
    if (digitalRead(BTN_LEFT) == LOW) {
      lastTickButtonPressed = 0;
    }
    else if (digitalRead(BTN_MIDDLE) == LOW) {
      lastTickButtonPressed = 1;
    }
    else if (digitalRead(BTN_RIGHT) == LOW) {
      lastTickButtonPressed = 2;
    }
  }

  if (lastUpdate == -1) {
    lastUpdate = getRtcTime();
  }

  display.begin(SSD1306_SWITCHCAPVCC, 0x3C);
  display.clearDisplay();
  display.display();
  display.setTextColor(SSD1306_WHITE);
}

enum Screen {
  SCREEN_MAIN, SCREEN_FEED, SCREEN_PLAY, SCREEN_SLEEP, SCREEN_INFO
};

Screen currentScreen = SCREEN_MAIN;
uint64_t lastScreenChange = 0;

void goSleep() {
  display.clearDisplay();
  display.display();

  display.ssd1306_command(SSD1306_DISPLAYOFF);
  display.ssd1306_command(0x8D);
  display.ssd1306_command(0x10);

  esp_sleep_enable_timer_wakeup(UPDATE_DELAY_IN_uS - (getRtcTime() - lastUpdate));
  esp_deep_sleep_start();
}

uint8_t lastButtonPresses[10] = {0};

void handleButtons() {
  if (millis() - lastButtonPress < 100) return;

  if (digitalRead(BTN_RIGHT) == LOW && lastButtonPresses[9] == 0 && lastButtonPresses[8] == 2 && lastButtonPresses[7] == 0 && lastButtonPresses[6] == 1 && lastButtonPresses[5] == 1) {
    digitalWrite(VIBRATION_MOTOR, HIGH);
    delay(5000);
    digitalWrite(VIBRATION_MOTOR, LOW);
  }

  if (digitalRead(BTN_LEFT) == LOW && lastButtonPresses[9] == 2 && lastButtonPresses[8] == 2 && lastButtonPresses[7] == 1 && lastButtonPresses[6] == 0 && lastButtonPresses[5] == 1) {
    currentScreen = SCREEN_INFO;
    display.clearDisplay();
    display.setCursor(0, 26);
    display.setTextColor(SSD1306_WHITE);
    display.print("Temp: ");
    display.print(getTempC());
    display.print("C");
    display.display();
  }

  uint8_t buttonPressed = 52;

  if (digitalRead(BTN_LEFT) == LOW) {
    buttonPressed = 0;
  }
  else if (digitalRead(BTN_MIDDLE) == LOW) {
    buttonPressed = 1;
  }
  else if (digitalRead(BTN_RIGHT) == LOW) {
    buttonPressed = 2;
  }

  if (buttonPressed != 52 && lastTickButtonPressed == 52) {
    if (currentScreen == SCREEN_MAIN) {
      if (buttonPressed == 0) {
        currentScreen = SCREEN_FEED;
        pet.hunger += 15;
        pet.energy += 5;
        if (pet.hunger > 100) {
          pet.hunger = 100;
        }

        lastScreenChange = millis();
        lastButtonPress = millis();
      }
      else if (buttonPressed == 1) {
        currentScreen = SCREEN_PLAY;
        pet.happiness += 15;
        pet.energy -= 5;
        if (pet.happiness > 100) {
          pet.happiness = 100;
        }

        lastScreenChange = millis();
        lastButtonPress = millis();
      }
      else if (buttonPressed == 2) {
        currentScreen = SCREEN_SLEEP;
        pet.energy += 15;
        if (pet.energy > 100) {
          pet.energy = 100;
        }

        lastScreenChange = millis();
        lastButtonPress = millis();
      }

      if (pet.energy < 0) {pet.energy = 0;}
      if (pet.happiness < 0) {pet.happiness = 0;}
      if (pet.hunger < 0) {pet.hunger = 0;}
    }

    else if (currentScreen == SCREEN_INFO) {
      currentScreen == SCREEN_MAIN;
    }

    for (int i = 0; i < sizeof(lastButtonPresses)-1; i++) {
      lastButtonPresses[i] = lastButtonPresses[i+1];
    }

    lastButtonPresses[sizeof(lastButtonPresses)-1] = buttonPressed;
  }

  lastTickButtonPressed = buttonPressed;
}

void drawBar(int x, int y, int value) {
  if (value < 10 && (millis()/500)%2 == 0) {return;}

  int width = 50;
  int height = 6;

  int fillWidth = map(value, 0, 100, 0, width);
  display.drawRect(x, y, width, height, SSD1306_WHITE);
  display.fillRect(x, y, fillWidth, height, SSD1306_WHITE);
}

void render() {
  if ((currentScreen == SCREEN_FEED || currentScreen == SCREEN_PLAY || currentScreen == SCREEN_SLEEP) && millis() - lastScreenChange > 3000) {
    currentScreen = SCREEN_MAIN;
  }

  switch (currentScreen)
  {
  case SCREEN_FEED:
    display.clearDisplay();
    display.setCursor(0,HEIGHT/2-4);
    display.print("Feeding blobfi");
    break;

  case SCREEN_PLAY:
    display.clearDisplay();
    display.setCursor(0,HEIGHT/2-4);
    display.print("Blobfi is playing");
    break;

  case SCREEN_SLEEP:
    display.clearDisplay();
    display.setCursor(0,HEIGHT/2-4);
    display.print("Blobfi is sleeping");
    break;
  
  case SCREEN_MAIN:
    const unsigned char* sprite;
    if (pet.hunger < 30 || pet.happiness < 30 || pet.energy < 30) {
      sprite = SAD_BLOBFI;
    } else if (pet.hunger > 65 && pet.happiness > 65 && pet.energy > 65) {
      sprite = HAPPY_BLOBFI;
    } else {
      sprite = NEUTRAL_BLOBFI;
    }
    display.clearDisplay();

    display.drawBitmap(78, 10, sprite, 32, 22, SSD1306_WHITE);

    display.setTextSize(1);

    display.setCursor(0, 0);
    display.print("Hunger");
    drawBar(0, 9, pet.hunger);

    display.setCursor(0, 18);
    display.print("Happiness");
    drawBar(0, 27, pet.happiness);

    display.setCursor(0, 36);
    display.print("Energy");
    drawBar(0, 45, pet.energy);

    display.setCursor(0, 56);
    display.print("[Feed] [Play] [Sleep]");
    break;

  case SCREEN_INFO:
    break;
  }

  if (currentScreen == SCREEN_FEED || currentScreen == SCREEN_PLAY || currentScreen == SCREEN_SLEEP) {
    for (int i = 0; i < (millis()/200)%4; i++) {
      display.print(".");
    }
  } 

  display.display();
}

void handleSleeping() {
  if (millis() - lastButtonPress > SLEEP_AFTER_INACTIVE_FOR_S * 1000) {
    goSleep();
  }
}

void updatePet() {
  pet.age++;
  pet.energy--;
  pet.happiness--;
  pet.hunger--;

  float temp = getTempC();

  if (temp > 40 || temp < 5) {
    pet.happiness--;
  }

  if (pet.energy < 0) {pet.energy = 0;}
  if (pet.happiness < 0) {pet.happiness = 0;}
  if (pet.hunger < 0) {pet.hunger = 0;}

  /*if (pet.energy == 0 || pet.happiness == 0 || pet.hunger == 0) {
    digitalWrite(VIBRATION_MOTOR, HIGH);
    delay(3000);
    digitalWrite(VIBRATION_MOTOR, LOW);
  }*/

  lastUpdate = getRtcTime();
}

void handleAwakeUpdating() {
  if (getRtcTime() - lastUpdate > UPDATE_DELAY_IN_uS) {
    updatePet();
  }
}

void loop() {
  handleButtons();
  render();
  handleSleeping();
  handleAwakeUpdating();
  delay(10);

  Serial.println(currentScreen);
}

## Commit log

2026-04-06 added 3d models
    [bottom-part.f3d, bottom-part.step, top-part.f3d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]
2026-04-22 add proper warning
    [blobfi.kicad_pcb, blobfi.kicad_sch]
2026-04-24 added temp sensor & vibration motor & time persistance after deep sleep
    [blobfi_firmware.ino]
2026-04-24 update BOM
    [BOM.csv]
2026-04-24 update PCB & remove old firmware
    [blobfi.kicad_pcb, blobfi_gerber_bom.csv, blobfi_gerber_designators.csv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]
2026-04-24 update CAD files
    [bottom-part.f3d, bottom-part.step, top-part.f3d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]
2026-04-25 update README and little changes in firmware & BOM
    [BOM.csv]
2026-04-26 update BOM & 3d model with new battery
    [BOM.csv, bottom-part.f3d, bottom-part.step]
2026-04-26 update BOM note
    [BOM.csv]
2026-04-26 remove useless Qty column in BOM
    [BOM.csv]
2026-04-26 remove unused note column in BOM
    [BOM.csv]
2026-04-26 add assembly
2026-05-08 removed fake coupon by jlcpcb from the BOM
2026-05-22 disable temp sensor & minor firmware improvements
2026-05-26 fixed temp sensor, now working
    [blobfi_firmware.ino]
2026-05-28 little CAD changes
    [bottom-part.f3d, bottom-part.step, screen-support.step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]
2026-06-01 updated with irl photos
    [BOM.csv]
